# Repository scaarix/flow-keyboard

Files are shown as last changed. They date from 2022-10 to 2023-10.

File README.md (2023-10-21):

# Flow
An open source split mechanical keyboard powered by [Ergogen](https://github.com/ergogen/ergogen) and kicad
## The board:
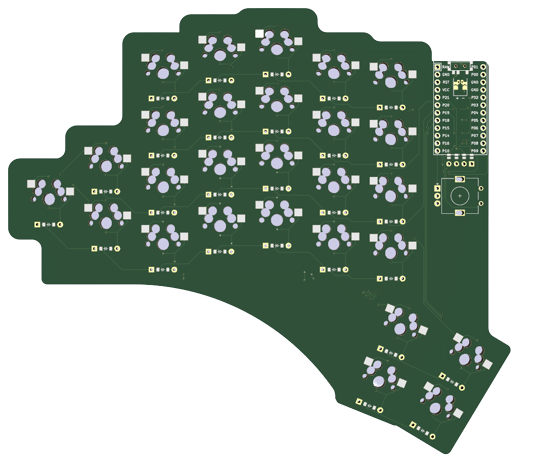
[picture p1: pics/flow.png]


# Updates
- REBUILDING THE DESIGN FROM THE GROUND UP
I didn't really like where I was going with this keyboard design and wanted to change the overall look and feel of the keyboard and the features that I want with this board
# Features
- Hotswappable with mx-style switches
- Flippable PCB
- 4 Key Thumb Cluster

## TODO
- [ ] Finish layout (ergogen)
- [ ] Make keyboard outline (ergogen) 
- [ ] Create pcb (ergogen)

# Goals
- Have hotswap with choc, kailh box etc.
- Be wireless
- Have RGB if I can actually configure it properly

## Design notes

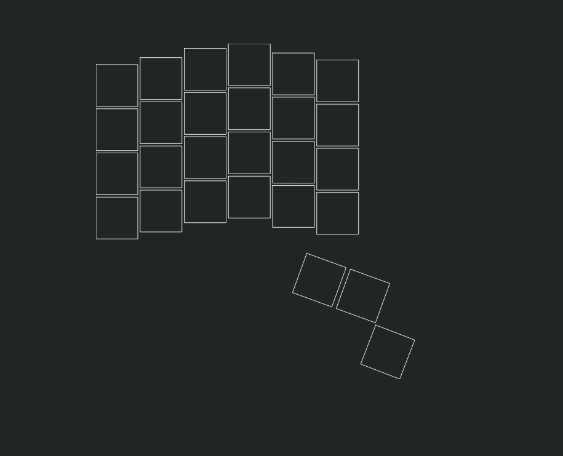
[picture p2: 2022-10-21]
flow.png

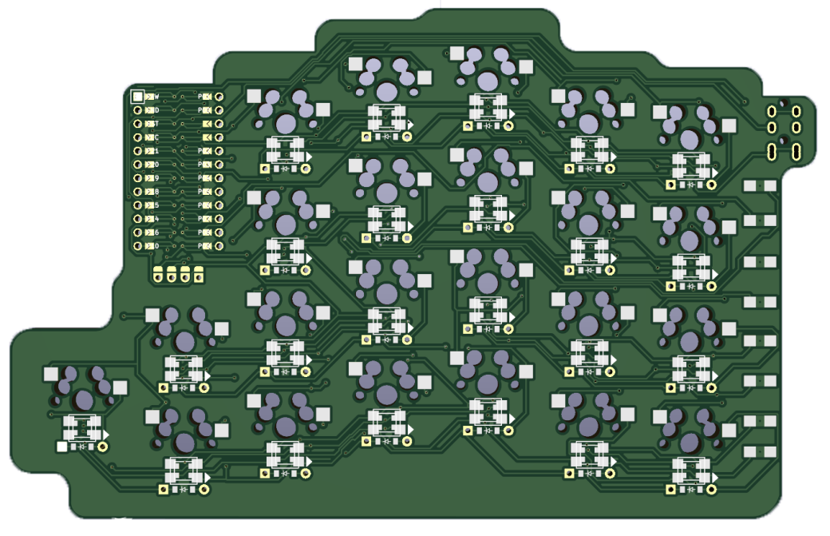
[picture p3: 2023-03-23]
pics/flow_v2.jpg

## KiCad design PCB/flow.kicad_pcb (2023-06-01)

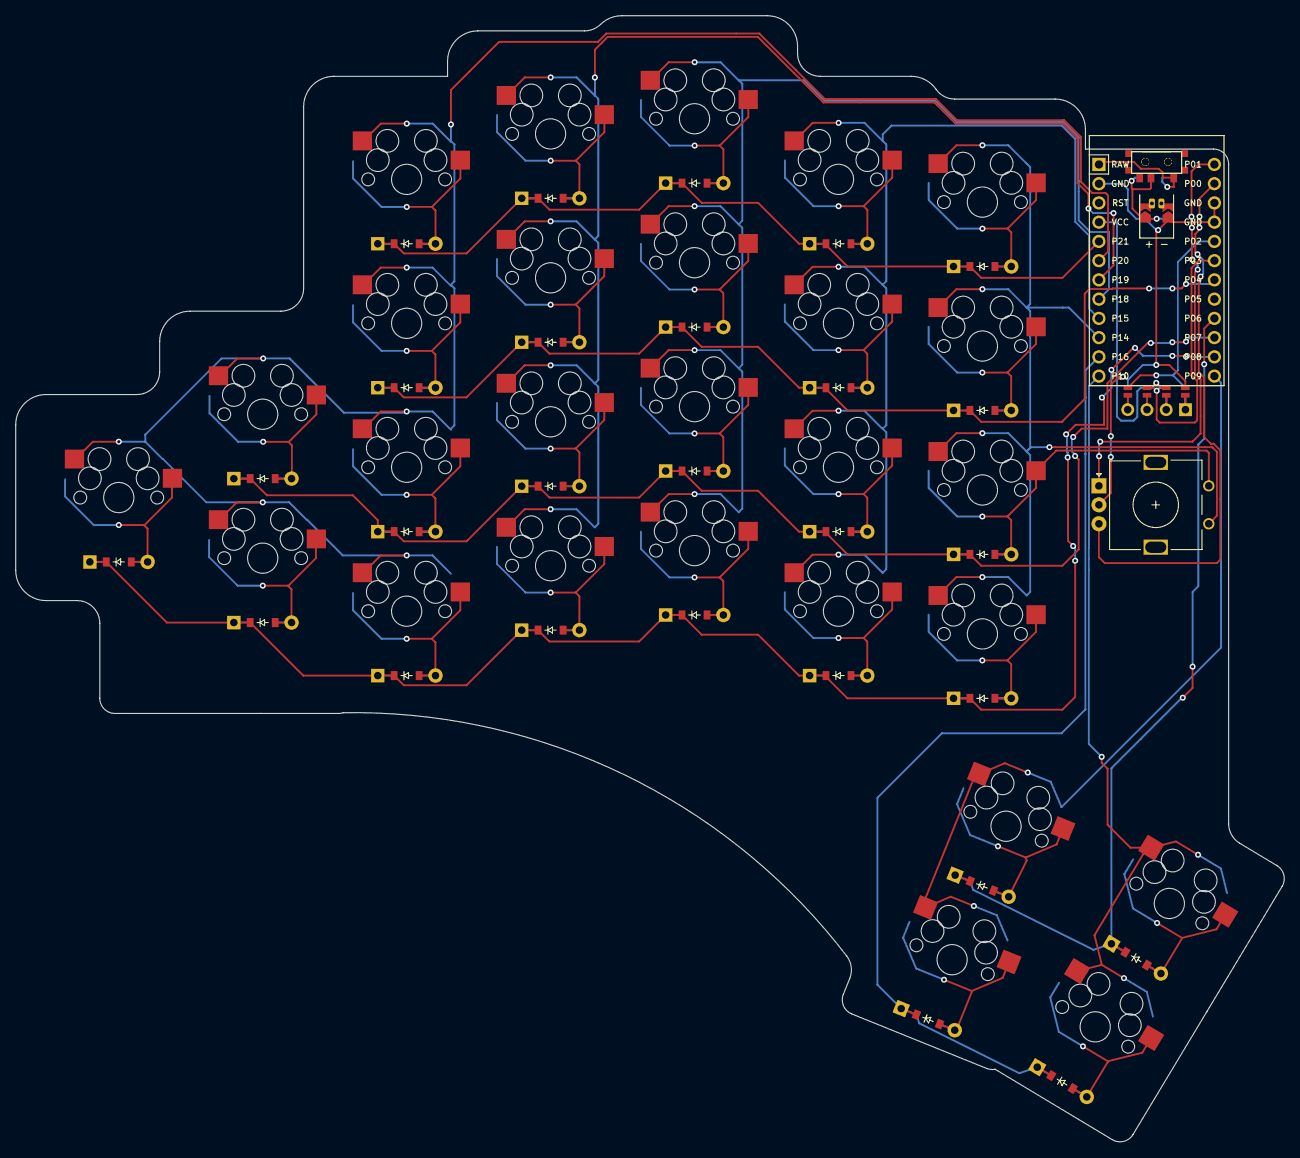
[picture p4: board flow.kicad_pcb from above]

Board: 2 copper layers, 167.4 x 148.6 mm, 68 parts (0 on the bottom side), 52 nets.

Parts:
D1, D2, D3, D4, D5, D6, D7, D8, D9, D10, D11, D12, D13, D14, D15, D16, D17, D18, D19, D20, D21, D22, D23, D24, D25, D26, D27: ComboDiode
J1, J2, J3, J4, J5, J6, J7, J8: Jumper
JST1: PicoBlade_Power_Reversible
MCU1: ProMicro
OLED1: OLED; OLED_headers
ROT1: rotary_encoder
S1, S2, S3, S4, S5, S6, S7, S8, S9, S10, S11, S12, S13, S14, S15, S16, S17, S18, S19, S20, S21, S22, S23, S24, S25, S26, S27: MX
T1, T2: SPDT_C128955

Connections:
1_bottom: D24.2, S24.1
1_top: D25.2, S25.1
2_bottom: D26.2, S26.1
2_top: D27.2, S27.1
BAT+: JST1.1, T1.2, T2.1
GND: J4.2, J5.2, JST1.1, MCU1.2, MCU1.15, MCU1.16, ROT1.C
P0: MCU1.14, ROT1.B
P1: MCU1.13, ROT1.A
P2: J1.2, J8.2, MCU1.17
P3: J2.2, J7.2, MCU1.18
P4: D6.1, D10.1, D14.1, D18.1, D22.1, MCU1.19
P6: D25.1, D27.1, MCU1.21
P7: D3.1, D5.1, D9.1, D13.1, D17.1, D21.1, MCU1.22
P8: D1.1, D2.1, D4.1, D8.1, D12.1, D16.1, D20.1, MCU1.23
P9: MCU1.24, S24.2, S25.2
P10: MCU1.12, S26.2, S27.2
P14: MCU1.10, ROT1.2, S20.2, S21.2, S22.2, S23.2
P15: MCU1.9, S16.2, S17.2, S18.2, S19.2
P16: D24.1, D26.1, MCU1.11
P18: MCU1.8, S12.2, S13.2, S14.2, S15.2
P19: MCU1.7, S8.2, S9.2, S10.2, S11.2
P20: MCU1.6, S1.2, S2.2, S3.2, S4.2, S5.2, S6.2, S7.2
P21: D7.1, D11.1, D15.1, D19.1, D23.1, MCU1.5
RAW: MCU1.1, T1.1, T2.2
VCC: J3.2, J6.2, MCU1.4
far_bottom: D20.2, S20.1
far_home: D21.2, ROT1.1, S21.1
far_num: D23.2, S23.1
far_top: D22.2, S22.1
index_bottom: D16.2, S16.1
index_home: D17.2, S17.1
index_num: D19.2, S19.1
index_top: D18.2, S18.1
middle_bottom: D12.2, S12.1
middle_home: D13.2, S13.1
middle_num: D15.2, S15.1
middle_top: D14.2, S14.1
oled1: J1.1, J5.1, OLED1.4
oled2: J2.1, J6.1, OLED1.3
oled3: J3.1, J7.1, OLED1.2
oled4: J4.1, J8.1, OLED1.1
pinkie_bottom: D4.2, S4.1
pinkie_home: D5.2, S5.1
pinkie_num: D7.2, S7.1
pinkie_top: D6.2, S6.1
ring_bottom: D8.2, S8.1
ring_home: D9.2, S9.1
ring_num: D11.2, S11.1
ring_top: D10.2, S10.1
single_bottom: D1.2, S1.1
tab_bottom: D2.2, S2.1
tab_home: D3.2, S3.1

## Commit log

2022-10-21 added trrs, fixed mcu changed pcb shape
2022-10-21 moved diodes and added space for screw holes
2022-10-22 made pcb tops bigger so keycaps weren't atop of case
2022-10-27 fixed diodes
2022-11-01 fixed pcb and trrs placement
2022-12-10 Changed routing a little and generated gerbers
    [scaarix_flow-B_Cu.gbr, scaarix_flow-B_Mask.gbr, scaarix_flow-B_Paste.gbr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]
2022-12-11 cleaned up a little
    [scaarix_flow-B_Cu.gbr, scaarix_flow-B_Mask.gbr, scaarix_flow-B_Paste.gbr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]
2022-12-11 Changed footprint and rerouted
    Used a different footprint that wasn't hotswappable. Changed it and Re-routed
    [scaarix_flow-B_Cu.gbr, scaarix_flow-B_Mask.gbr, scaarix_flow-B_Paste.gbr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]
2022-12-11 Fixed stabilizers
    Stab orientation was wrong
    [scaarix_flow-B_Cu.gbr, scaarix_flow-B_Mask.gbr, scaarix_flow-B_Paste.gbr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]
2023-01-27 made switches and diodes actually appear
2023-01-29 starting to work on aesthetics of pcb
    may change to rp2040 for a diode-less design
    tbd
2023-01-30 FINISHED
    This version is v2 wired, oled and non rgb
2023-02-01 routed pcb with freerouting and generated gerbers for pcb printing
    [freerouting.dsn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]
2023-02-01 separated thumb cluster, main body and bridge
    this is used to for actually printing the pcb :)
    [scaarix_flow.kicad_pcb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]
2023-02-01 added gerbers that I forgot to add
    [scaarix_flow-B_Cu.gbr, scaarix_flow-B_Mask.gbr, scaarix_flow-B_Paste.gbr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]
2023-02-09 added switch plates & their gerbers
    [scaarix_flow-B_Cu.gbr, scaarix_flow-B_Mask.gbr, scaarix_flow-B_Paste.gbr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]
2023-02-09 added switch plate & gerbers
    [scaarix_flow_thumb_cluster-B_Cu.gbr, scaarix_flow_thumb_cluster-B_Mask.gbr, scaarix_flow_thumb_cluster-B_Paste.gbr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]
2023-05-14 added updated version of the keyboard design
    Rebuilding what was previously bad and needed work. Now adding Oled, and wireless
2023-05-15 fixed slider and added BAT+ to the battery
2023-05-16 fixed the "from" in the rotary encoder. Have to add diodes now
2023-05-18 fixed rotary encoder position
2023-05-22 added jumpers for oled and added second side to on/off switch
2023-05-24 moved files
    [scaarix_flow.kicad_pcb]
2023-05-24 moved gerbers
    [scaarix_flow-B_Cu.gbr, scaarix_flow-B_Mask.gbr, scaarix_flow-B_Paste.gbr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]
2023-05-25 Update flow_keyboard
2023-05-27 fixed rotary encoder positioning
2023-05-29 fixed rotary encoder pins
2023-06-01 fixed board outline
2023-06-29 changed sizing to accommodate screw holes
2023-08-25 added case bottom
2023-08-25 added screw holes
2023-08-25 started working on plate
